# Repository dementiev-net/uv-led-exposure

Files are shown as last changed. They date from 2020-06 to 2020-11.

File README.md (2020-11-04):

LED засветка фоторезиста и паяльной маски
=====================

Это система состоящая из контроллера и матрицы для засветки фоторезиста и паяльной защитной маски. 

| Контроллер | Матрица
|---|---
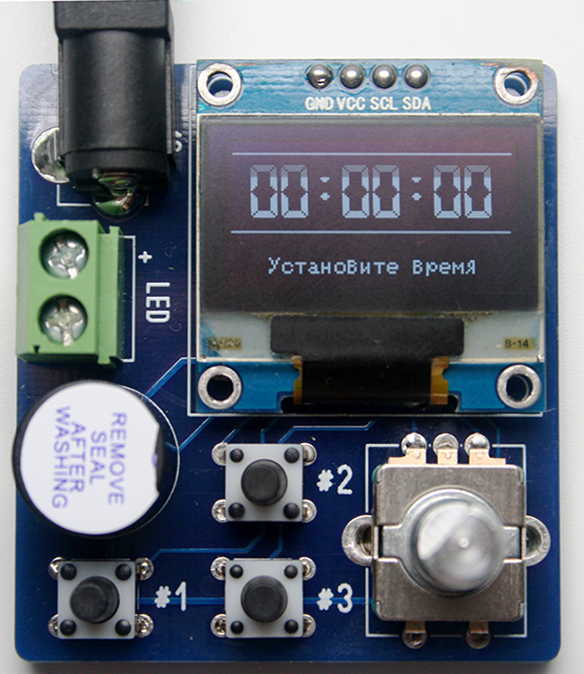
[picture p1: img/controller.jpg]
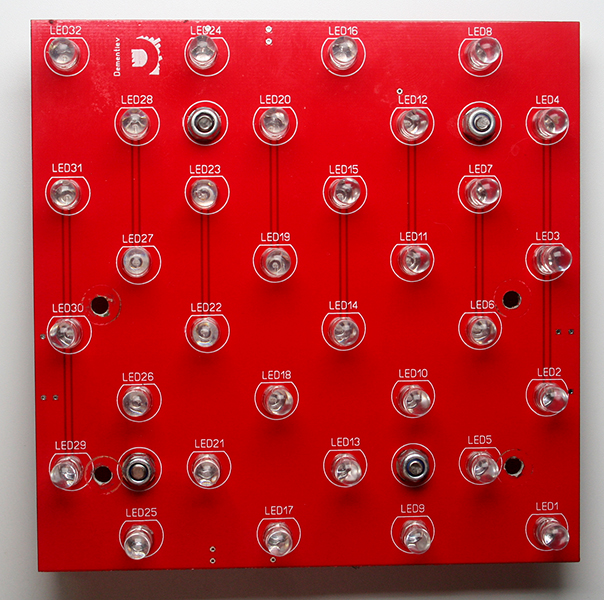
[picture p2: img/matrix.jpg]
|  | 

## Плата матрицы

Плата матрицы размера 10 на 10 см. имеет 32 светодиода подключенные в цепочки по 4 штуки через резистор. Из нескольких плат можно собрать матрицу любой площади. Платы спаиваются между собой с помощью площадок.

| Верх | Низ
|---|---
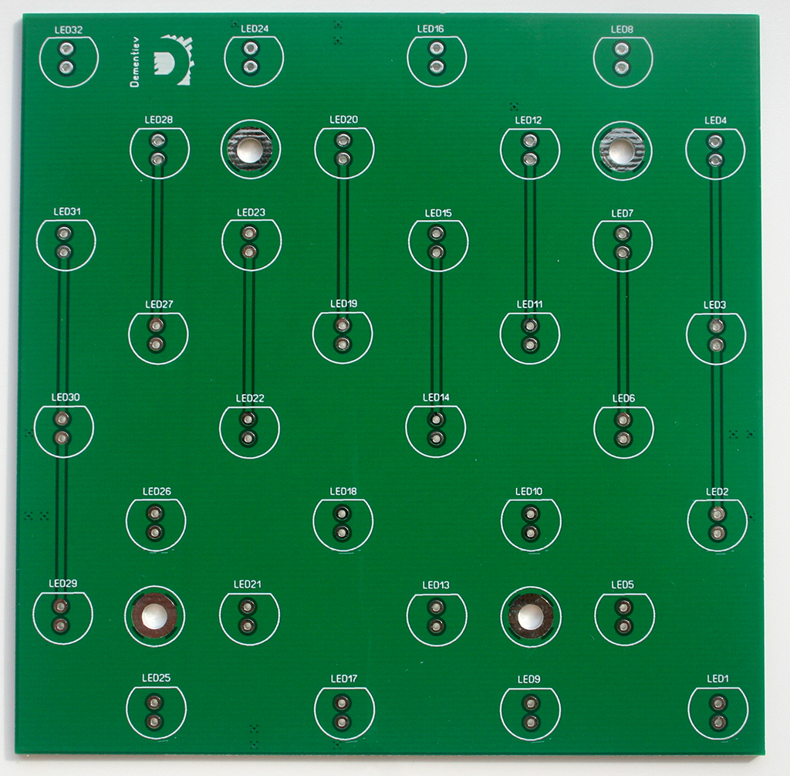
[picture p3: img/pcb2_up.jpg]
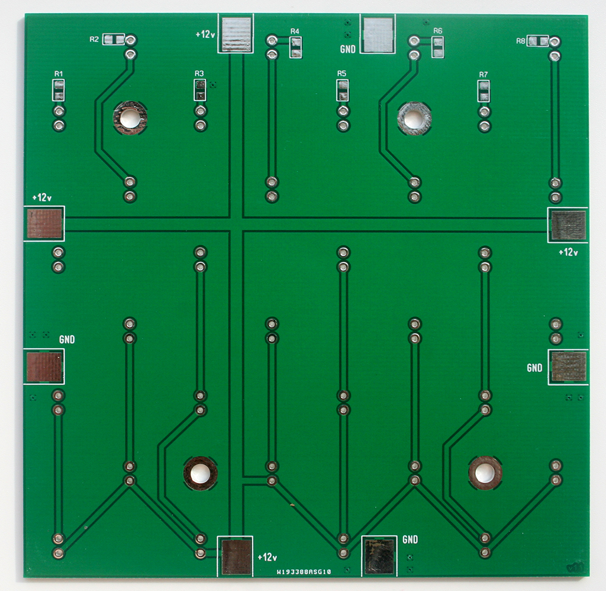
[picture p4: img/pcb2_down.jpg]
|  | 

#### BOM:

|No|Name|Value|Layer|Comment
|---|---|---|---|---
|1|D1-D32|LED|Top|5mm
|2|R1-R8|62R *|Bottom|0805, номинал рассчитывается

## Плата контроллера

Контроллер имеет 3 кнопки пресета (актуально для маски, и нескольких видов фоторезиста т.к. время засветки у них отличается) и энкодер для установки времени вручную.

| Верх | Низ
|---|---
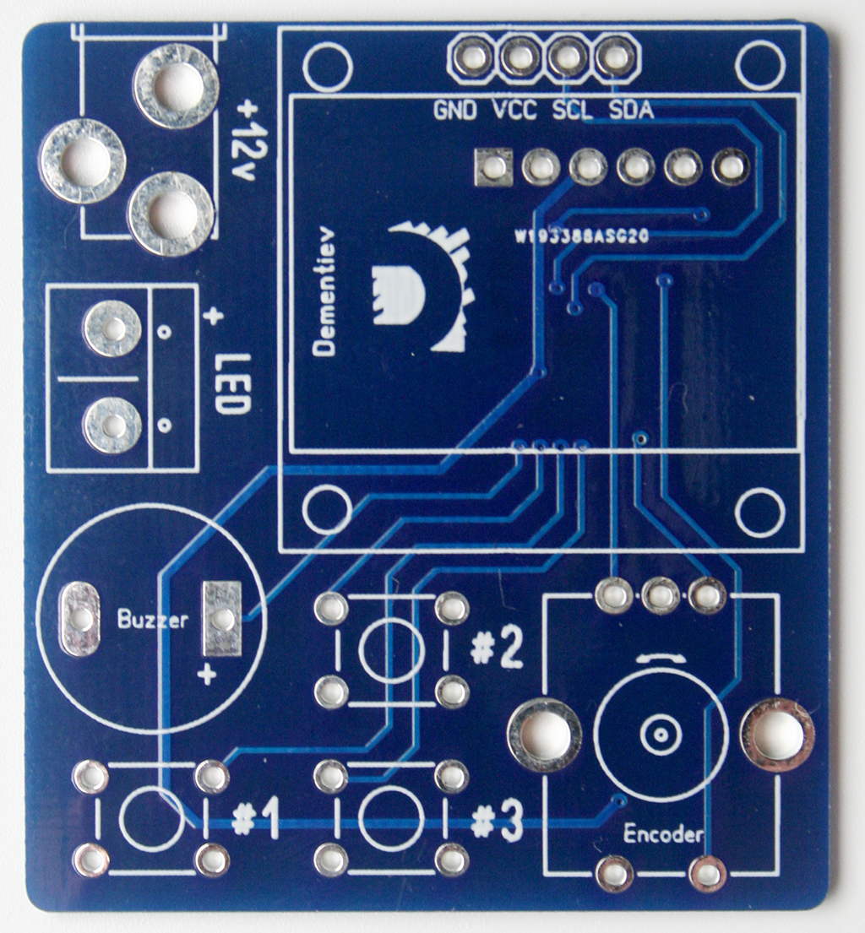
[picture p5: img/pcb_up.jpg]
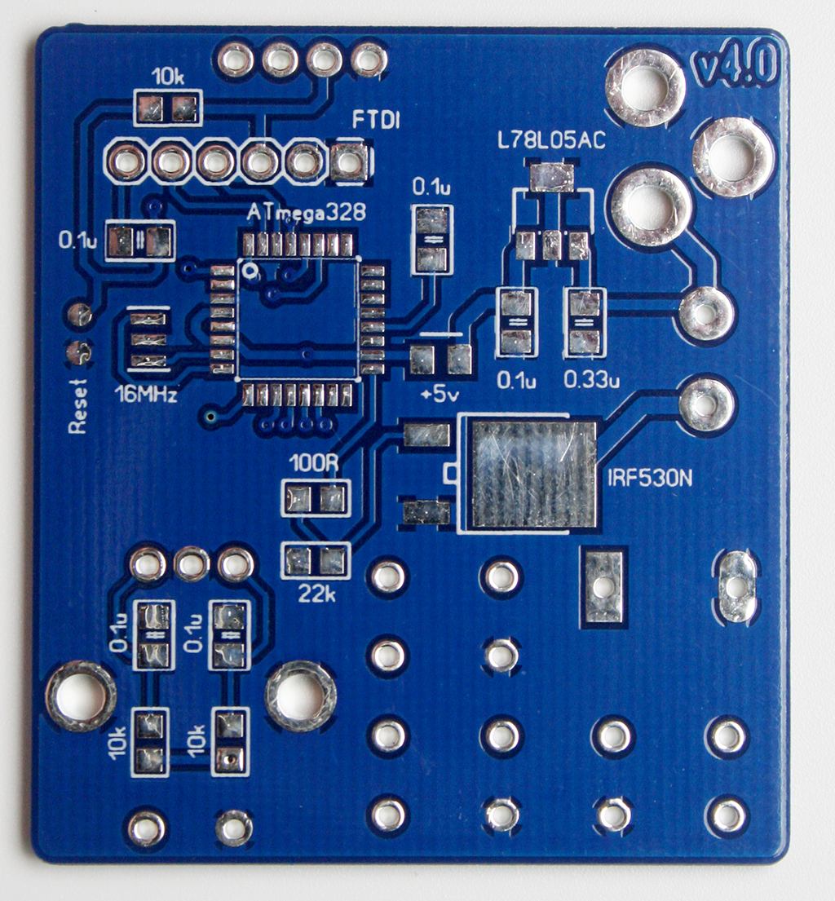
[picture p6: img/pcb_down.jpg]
|  | 

#### Управление:

* При нажатии на **любую из трех кнопок** происходит выбор пресета времена засветки;
* Для создания пресета нужно выбрать энкодером время и удерживать **кнопоку** в течении 3 секунд;
* **Энкодер** выбирает время вручную с шагом 5 секунд (задается в прошивке). При **нажатии на энкодер** запускается засветка. По окончании прозвучит звуковой сигнал;

#### BOM:

|No|Name|Value|Layer|Comment
|---|---|---|---|---
|1|B1,B2,B3|Button|Top|
|2|C1,C2,C3,C4,С5|0.1u|Bottom|0805
|3|C6|0.33u|Bottom|0805
|4|Q1|Buzzer|Top|5v
|5|Q2|16Mhz|Bottom|
|6|R1|100R|Bottom|0805
|7|R2,R3,R4|10k|Bottom|0805
|8|R5|22k|Bottom|0805
|9|S1|DS-261B|Top|
|10|S2|301-021-12|Top|
|11|S3|Encoder|Top|
|12|SCREEN|0.96 OLED|Top|I2C 128x64
|13|U1|Atmega328|Bottom|TQFP-32
|14|U2|IRF530N|Bottom|D-PAK
|15|U3|L78L05|Bottom|SOT-89

## Корпус

Корпус распечатан на 3D принтере. Предназначен для удобного крепления контроллера к матрице. В принципе можно использовать двусторонний скотч.

| Корпус | Сборка
|---|---
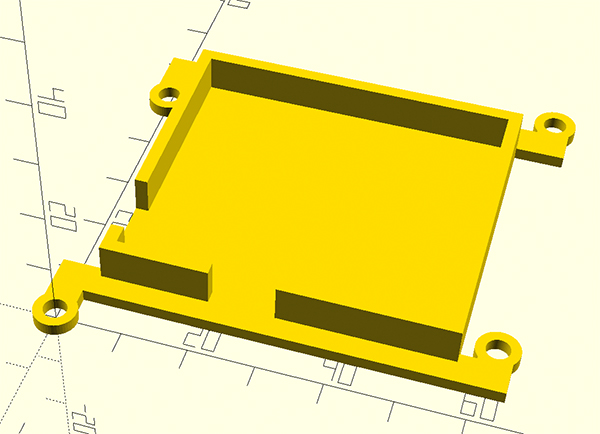
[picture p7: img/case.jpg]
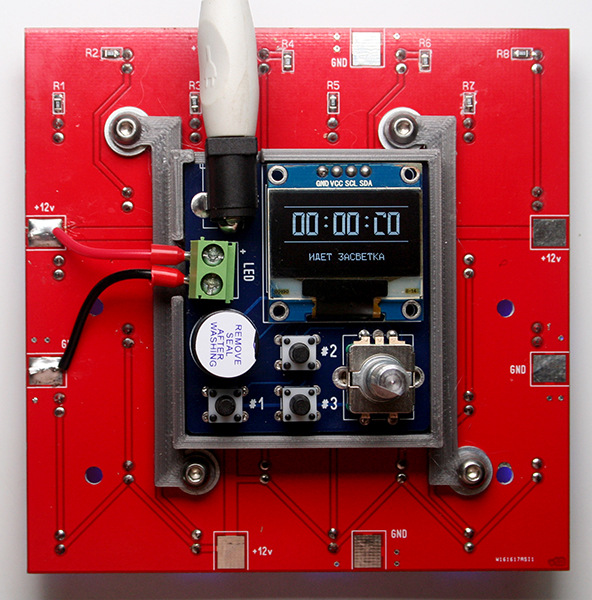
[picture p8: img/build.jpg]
|  | 

## Расчет светодиодов

Светодиоды бывают разные по характеристикам соответственно и резисторы будут отличаться по номиналу.

###### Пример:

Имеем китайский светодиод с напряжением 3.4 вольта и током потребления 25 миллиампер (бывают от 3.2 до 3.8 вольт, смотрите описание у продавца). Теперь в [калькуляторе расчета резисторов для светодиодов](https://cxem.net/calc/ledcalc.php) вводим наши данные. Т.к. вольтаж одного диода 3.4 вольта, а 4-х в цепочку соответственно 13,3 то питать матрицу будем от 15 вольт и резисторы выбирает на это напряжение.
Получаем 62 Ома. Но плату будем питать от 12 вольт. На времени засветки это отразится не значительно, но светодиоды проживут дольше.

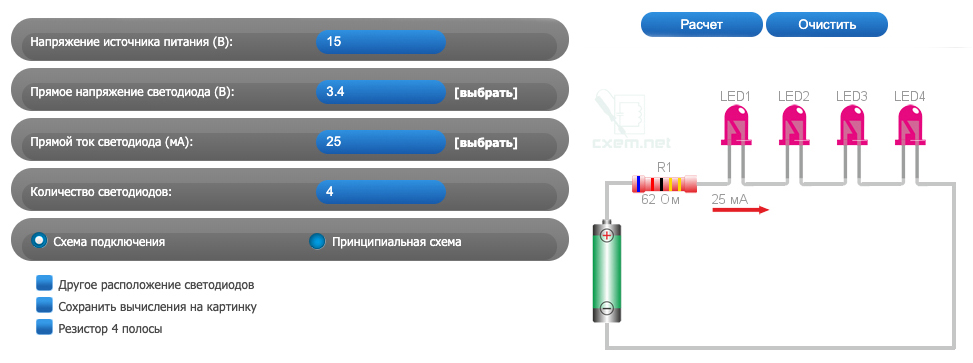
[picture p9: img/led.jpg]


## Прошивка

* Любым программатором загружается bootloader (HEX файл и фьюзы прилагаются). Самой простой вариант прошить через USB Arduino NANO и "сдуть" с нее чип.
* Впаивается чип на плату.
* Заливается INO файл из Arduino IDE (как Arduino NANO) с помощью USB-UART преобразователя (FTDI).

## Контакты

Связаться со мной: info@dementiev.net

##### Лицензия: «Attribution-NonCommercial-ShareAlike»<br>(«Атрибуция — Некоммерческое использование — На тех же условиях») 4.0 Всемирная



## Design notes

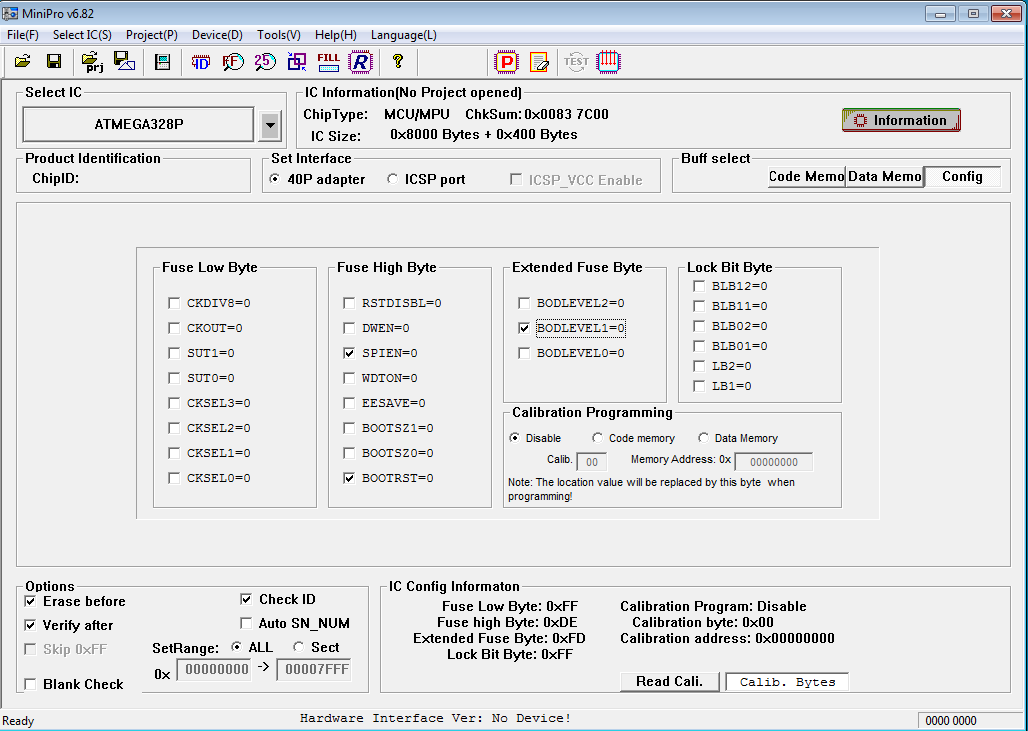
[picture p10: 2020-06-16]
bootloader/fuses.png

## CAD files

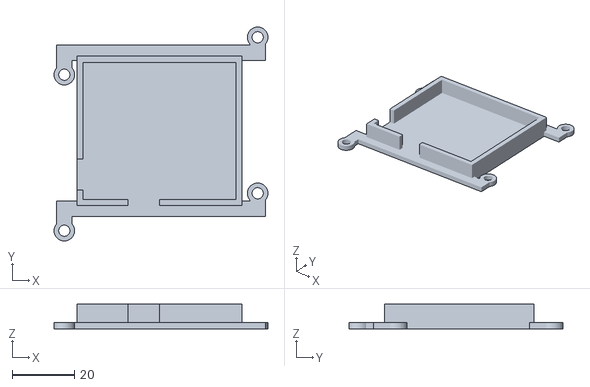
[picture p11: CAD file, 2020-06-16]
3d print/base.stl
68.6 x 68.6 x 8.00

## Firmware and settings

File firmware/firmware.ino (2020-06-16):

// ----------------------------------------------------------------------------
// LED засветка фоторезиста и паяльной маски
// версия 4.0 (Atmega328)
// (c) 2020 Дмитрий Дементьев <dementiev@me.com>
// ----------------------------------------------------------------------------

#include <EEPROM.h>
#include "config.h"
#include "button.h"
#include "lcd.h"

LCD lcd;
LCDData dataScreen;
BUTTON button1;
BUTTON button2;
BUTTON button3;

int Presets[] = {0, 0, 0};
unsigned long currentTime;   // текущее время
unsigned long loopTime;      // время окончания
unsigned long LimitTime = 0; // таймер
volatile boolean turn;
volatile boolean up;
int mode = 0; // флаг запуска отсчета

void setup()
{
  firstRun();
  Presets[0] = EEPROM.read(0); // берем пресеты из EEPROM
  Presets[1] = EEPROM.read(1);
  Presets[2] = EEPROM.read(2);
  for (int i = 0; i < 2; i++)
  {
    if (Presets[i] < 0 || Presets[i] > 86400) Presets[i] = 0;
  }
  pinMode(5, INPUT); // входы
  pinMode(2, INPUT);
  pinMode(3, INPUT);
  digitalWrite(3, HIGH);
  pinMode(8, INPUT);
  digitalWrite(8, HIGH);
  pinMode(9, INPUT);
  digitalWrite(9, HIGH);
  pinMode(7, INPUT);
  digitalWrite(7, HIGH);
  pinMode(13, OUTPUT);
  attachInterrupt(0, isr, CHANGE); // прерывание энкодера
  currentTime = millis();
  lcd.init();
  lcd.splashScreen();
  delay(1000);
}

void loop()
{
  /**
   * режим отсчета
   */
  if (mode == 1)
  {
    digitalWrite(13, HIGH); // включаем
    tone(10, BUZ_TONE, BUZ_TIME1); // звук

    currentTime = millis();
    loopTime = currentTime + LimitTime * 1000;
    while (currentTime < loopTime)
    {
      int h = LimitTime / 60 / 60;
      int m = LimitTime / 60 % 60;
      int s = LimitTime % 60;

      sprintf(dataScreen.txtTime, "%02d.%02d.%02d", h, m, s);
      sprintf(dataScreen.txtHelp, "%s", "BLTN PFCDTNRF");

      LimitTime = (loopTime - currentTime) / 1000;
      currentTime = millis();

      lcd.updateScreen(&dataScreen);
    }

    digitalWrite(13, LOW); // отключаем
    tone(10, BUZ_TONE, BUZ_TIME2); // звук
    lcd.resultScreen("PFRJYXTYJ");
    delay(3000);
    mode = 0;

  /**
   * режим выбора времени
   */
  }
  else
  {
    digitalWrite(13, LOW); // отключаем

    if (LimitTime > 86400) LimitTime = 0;
    int h = LimitTime / 60 / 60;
    int m = LimitTime / 60 % 60;
    int s = LimitTime % 60;

    sprintf(dataScreen.txtTime, "%02d.%02d.%02d", h, m, s);
    if (h == 0 && m == 0 && s == 0) sprintf(dataScreen.txtHelp, "%s", "Ecnfyjdbnt dhtvz");
    else                            sprintf(dataScreen.txtHelp, "%s", "Yf;vbnt CNFHN");

    buttonPress(1, button1.checkButton(8));
    buttonPress(2, button2.checkButton(9));
    buttonPress(3, button3.checkButton(7));

    if (turn)
    {
      // Энкодеры бывают разных типов. Если при вращении вправо время уменьшается
      // то здесь нужно поправить += на -= и наоборот
      if (up) LimitTime += SEC_STEP; else LimitTime -= SEC_STEP;
      turn = false;
      if (LimitTime < 0) LimitTime = 0;
    }
    // кнопка энкодера
    if (digitalRead(3) == LOW) mode = true;

    lcd.updateScreen(&dataScreen);
    delay(250);
  }
}

// прерывание энкодера
void isr()
{
  up = (digitalRead(5) == digitalRead(2));
  turn = true;
}

// кнопки пресетов
void buttonPress(int btnNumm, int clkType)
{
  int i = btnNumm - 1;

  // нажатие на кнопку
  if (clkType == 1)
  {
    char stroka[20];
    sprintf(stroka, "Ds,hfkb #%d", btnNumm);
    LimitTime = Presets[i];
    lcd.resultScreen(stroka);
    delay(1000);
  }
  // долгое нажатие. сохранили
  if (clkType == 3)
  {
    EEPROM.update(i, LimitTime);
    Presets[i] = LimitTime;
    lcd.resultScreen("Cj[hfytyj!");
    delay(1000);
  }
}

// первый запуск
bool firstRun()
{
  for (uint16_t i; i < sizeof(Presets); i++)
  {
    if (EEPROM.read(i) != 255) return false;
  }
  for (int i = 0; i < 5; i++)
  {
    EEPROM.update(i, 0);
  }
}

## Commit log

2020-06-16 Вторая версия
2020-06-16 Третья версия
    [Insulator.stl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]
2020-06-16 Четвертая версия
    [Insulator.stl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]
2020-11-04 Поменял описание
2020-11-17 Повторная выгрузка на Github
    [UV LED Exposure-[1.3].DRL, UV LED Exposure-[1.3]_copper_bottom.gbr, UV LED Exposure-[1.3]_copper_top.gbr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]
